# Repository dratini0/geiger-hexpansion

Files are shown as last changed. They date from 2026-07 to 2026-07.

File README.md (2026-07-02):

# Geiger counter hexpansion

## High voltage generator

The high voltage power supply uses a microcontroller PWM peripheral, and a uses an ADC for feedback.
This means that it can only work on the ADC side of the Tildagon.
It also means that the power supply is completely dependent on software.

## Buzzer

Instead of connecting the speaker directly to the pulse detector, it is attached to the MCU.
This way, the clicking can be muted in software.
Alternatively, there is a solder jumper to short.

## Acknowledgements

Uses the [hexpansion template from EMF](https://github.com/emfcamp/badge-2024-hardware/tree/main/hexpansion)

Schematic loosely based on [Mightyohm's](https://mightyohm.com/blog/products/geiger-counter/) and [BroHogan's](https://sites.google.com/site/diygeigercounter/home) designs.

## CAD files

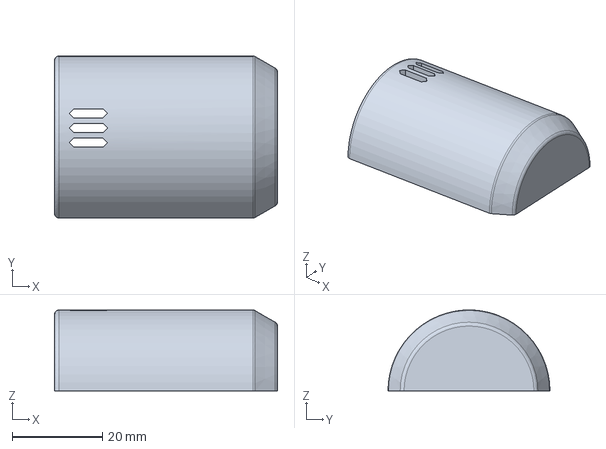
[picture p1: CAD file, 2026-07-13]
casing.FCStd
49.6 x 36.0 x 18.0 mm

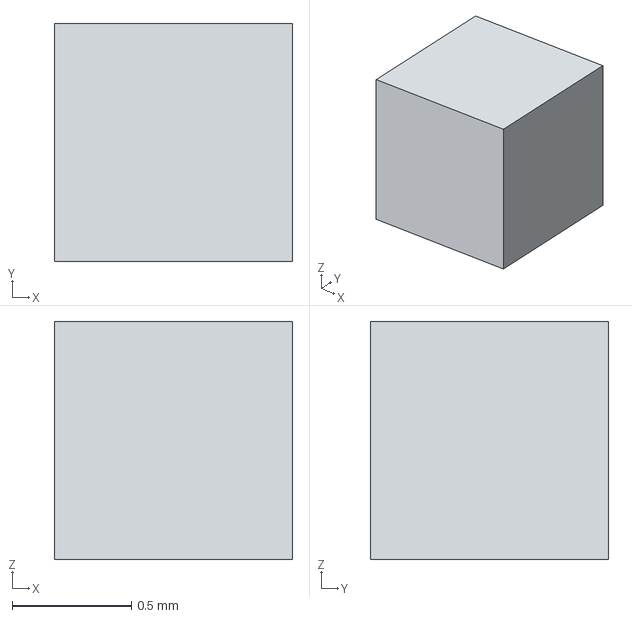
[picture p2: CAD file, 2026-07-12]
cube.stp
1.00 x 1.00 x 1.00 mm

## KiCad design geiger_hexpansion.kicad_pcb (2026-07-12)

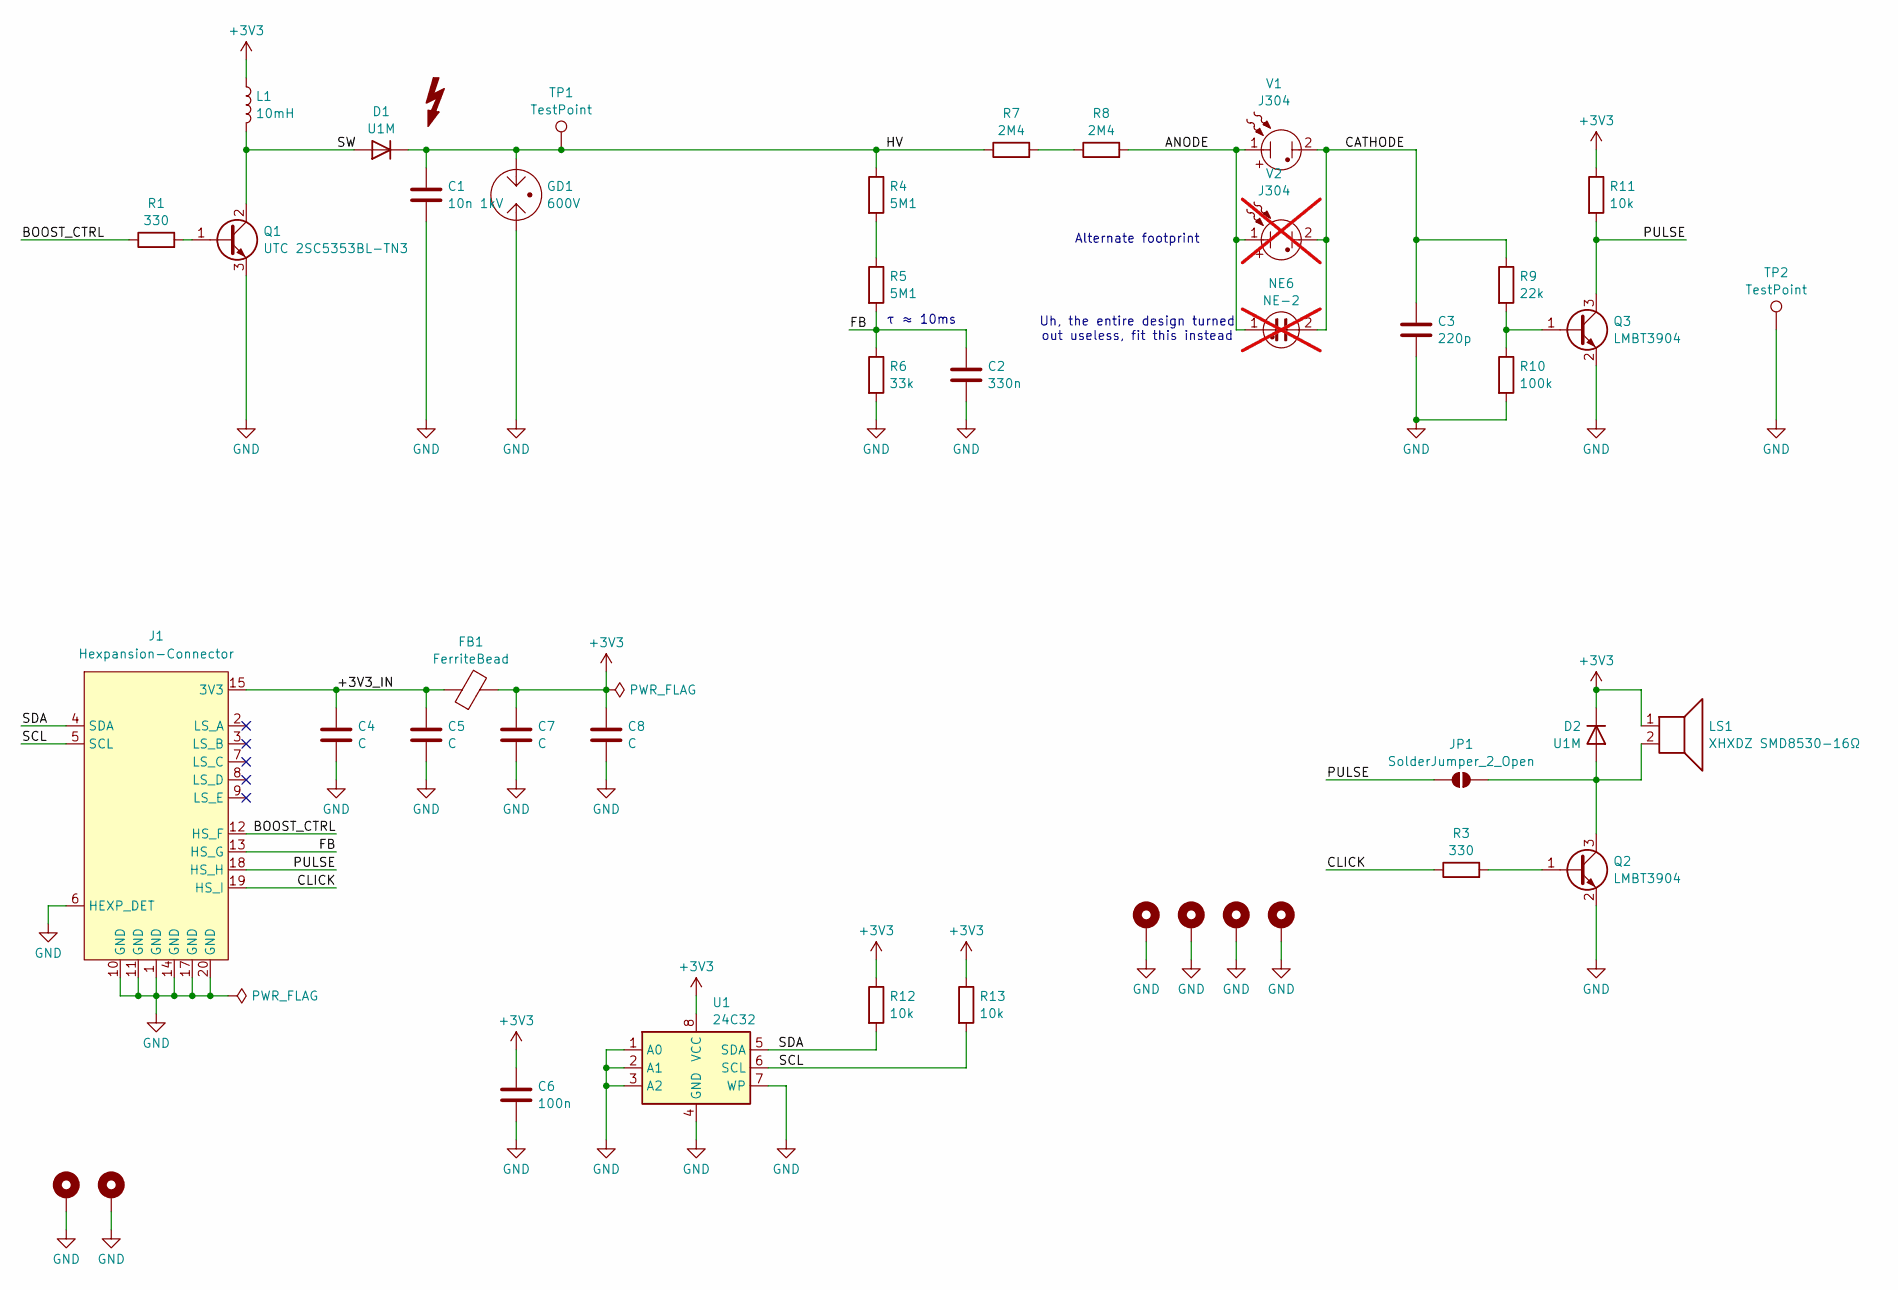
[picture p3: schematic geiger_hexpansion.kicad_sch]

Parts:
C1: 10n 1kV; C_1206_3216Metric_Pad1.33x1.80mm_HandSolder; LCSC C107192
C2: 330n; C_0805_2012Metric_Pad1.18x1.45mm_HandSolder
C3: 220p; C_0805_2012Metric_Pad1.18x1.45mm_HandSolder
C4, C5, C7, C8: C; C_0805_2012Metric_Pad1.18x1.45mm_HandSolder
C6: 100n; C_0805_2012Metric_Pad1.18x1.45mm_HandSolder
D1, D2: U1M; D_SOD-123F; LCSC C53222325
FB1: FerriteBead; L_0805_2012Metric_Pad1.05x1.20mm_HandSolder
GD1: 600V; 4532-601-LF; LCSC C41784202
H1, H2: MountingHole_Pad; MountingHole_2.2mm_M2_Pad_Via
H3, H4, H5, H6: MountingHole_Pad; MountingHole_3.2mm_M3_Pad_Via
J1: Hexpansion-Connector; hexpansion-edge-connector
JP1: SolderJumper_2_Open; SolderJumper-2_P1.3mm_Open_TrianglePad1.0x1.5mm
L1: 10mH; L_Ferrocore_DLG-0705; MPN ZE ZECD75-103K; LCSC C41422284
LS1: XHXDZ SMD8530-16Ω; XHXDZ_SMD8530; LCSC C49246948
NE6: NE-2; PinHeader_1x02_P2.54mm_Vertical; not fitted
Q1: UTC 2SC5353BL-TN3; TO-252-2; LCSC C73311
Q2, Q3: LMBT3904; SOT-23; LCSC C49580
R1, R3: 330; R_0805_2012Metric_Pad1.20x1.40mm_HandSolder
R4, R5: 5M1; R_1206_3216Metric_Pad1.30x1.75mm_HandSolder; LCSC C873653
R6: 33k; R_0805_2012Metric_Pad1.20x1.40mm_HandSolder
R7, R8: 2M4; R_1206_3216Metric_Pad1.30x1.75mm_HandSolder; LCSC C326957
R9: 22k; R_0805_2012Metric_Pad1.20x1.40mm_HandSolder
R10: 100k; R_0805_2012Metric_Pad1.20x1.40mm_HandSolder
R11, R12, R13: 10k; R_0805_2012Metric_Pad1.20x1.40mm_HandSolder
TP1, TP2: TestPoint; TestPoint_Pad_D1.5mm
U1: 24C32; SOIC-8_3.9x4.9mm_P1.27mm
V1: J304; E10_SMD
V2: J304; E10_THT; not fitted

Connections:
+3V3: C6.1, C7.1, C8.1, D2.1 (K), FB1.2, L1.1, LS1.1, R11.1, R12.1, R13.1, U1.8 (VCC)
/+3V3_IN: C4.1, C5.1, FB1.1, J1.15 (3V3), J1.16 (3V3)
/ANODE: NE6.1, R8.2, V1.1, V2.1
/BOOST_CTRL: J1.12 (HS_F), R1.1
/CATHODE: C3.1, NE6.2, R9.1, V1.2, V2.2
/CLICK: J1.19 (HS_I), R3.1
/FB: C2.1, J1.13 (HS_G), R5.2, R6.1
/HV: C1.1, D1.1 (K), GD1.3, R4.1, R7.1, TP1.1 (1_1)
/PULSE: J1.18 (HS_H), JP1.1 (A), Q3.3 (C), R11.2
/SCL: J1.5 (SCL), R13.2, U1.6 (SCL)
/SDA: J1.4 (SDA), R12.2, U1.5 (SDA)
/SW: D1.2 (A), L1.2, Q1.2 (C)
GND: C1.2, C2.2, C3.2, C4.2, C5.2, C6.2, C7.2, C8.2, GD1.1, H1.1 (1_1), H2.1 (1_1), H3.1 (1_1), H4.1 (1_1), H5.1 (1_1), H6.1 (1_1), J1.1 (GND), J1.6 (HEXP_DET), J1.10 (GND), J1.11 (GND), J1.14 (GND), J1.17 (GND), J1.20 (GND), Q1.3 (E), Q2.2 (E), Q3.2 (E), R6.2, R10.2, TP2.1 (1_1), U1.1 (A0), U1.2 (A1), U1.3 (A2), U1.4 (GND), U1.7 (WP)
unnamed: D2.2 (A), JP1.2 (B), LS1.2, Q2.3 (C)
unnamed: Q1.1 (B), R1.2
unnamed: Q2.1 (B), R3.2
unnamed: Q3.1 (B), R9.2, R10.1
unnamed: R4.2, R5.1
unnamed: R7.2, R8.1

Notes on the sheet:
Alternate footprint
τ ≈ 10ms
Uh, the entire design turned out useless, fit this instead

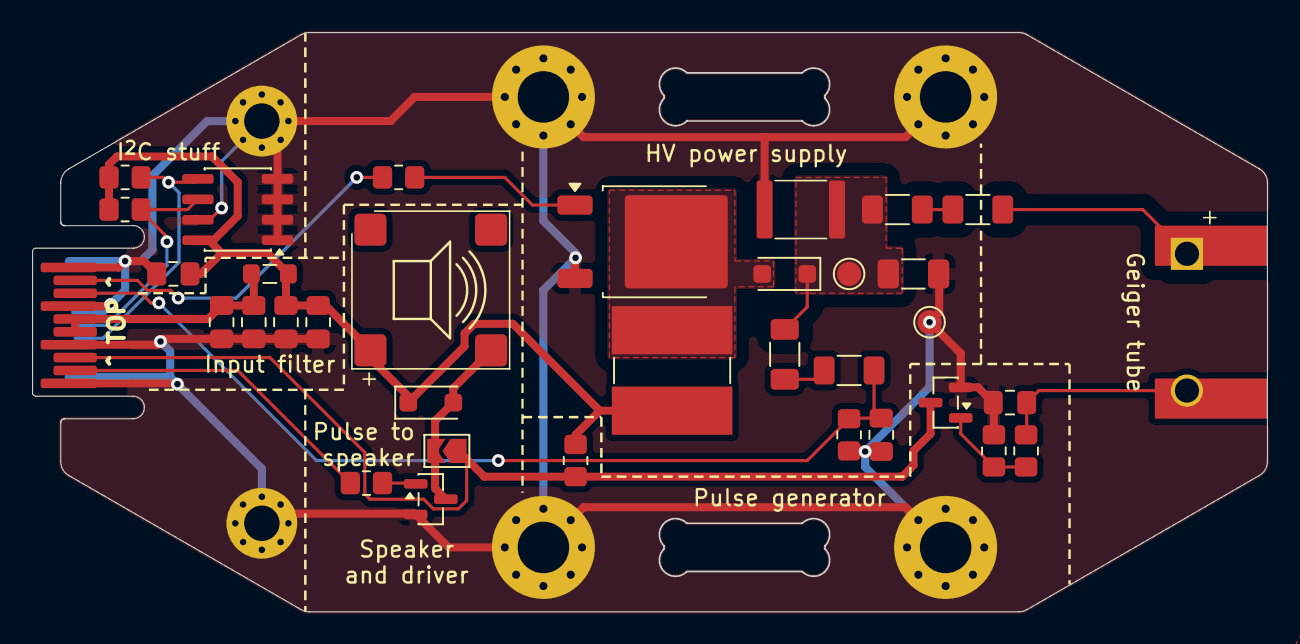
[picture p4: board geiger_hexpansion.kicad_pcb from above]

Board: 2 copper layers, 76.8 x 36.0 mm, 42 parts (0 on the bottom side), 19 nets.

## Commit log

2026-07-02 v1, as sent to fab
    [geiger_hexpansion.kicad_pcb, geiger_hexpansion.kicad_sch]
2026-07-12 casing, version 1
    [casing.FCStd, cube.stp, geiger_hexpansion.kicad_pcb]
2026-07-13 alter speaker holes
    [casing.FCStd]
